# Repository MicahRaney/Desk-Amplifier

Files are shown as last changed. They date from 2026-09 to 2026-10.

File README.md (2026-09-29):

View this project on [CADLAB.io](https://cadlab.io/project/30623). 

All the desktop amps are either too cheap (passive), or too expensive (too many features).

This is a project to see if I can build what I want: a 3 input / 1 output simple mixer/amp
to allow my desk speakers to play audio from my laptop, desktop, and CD player at once

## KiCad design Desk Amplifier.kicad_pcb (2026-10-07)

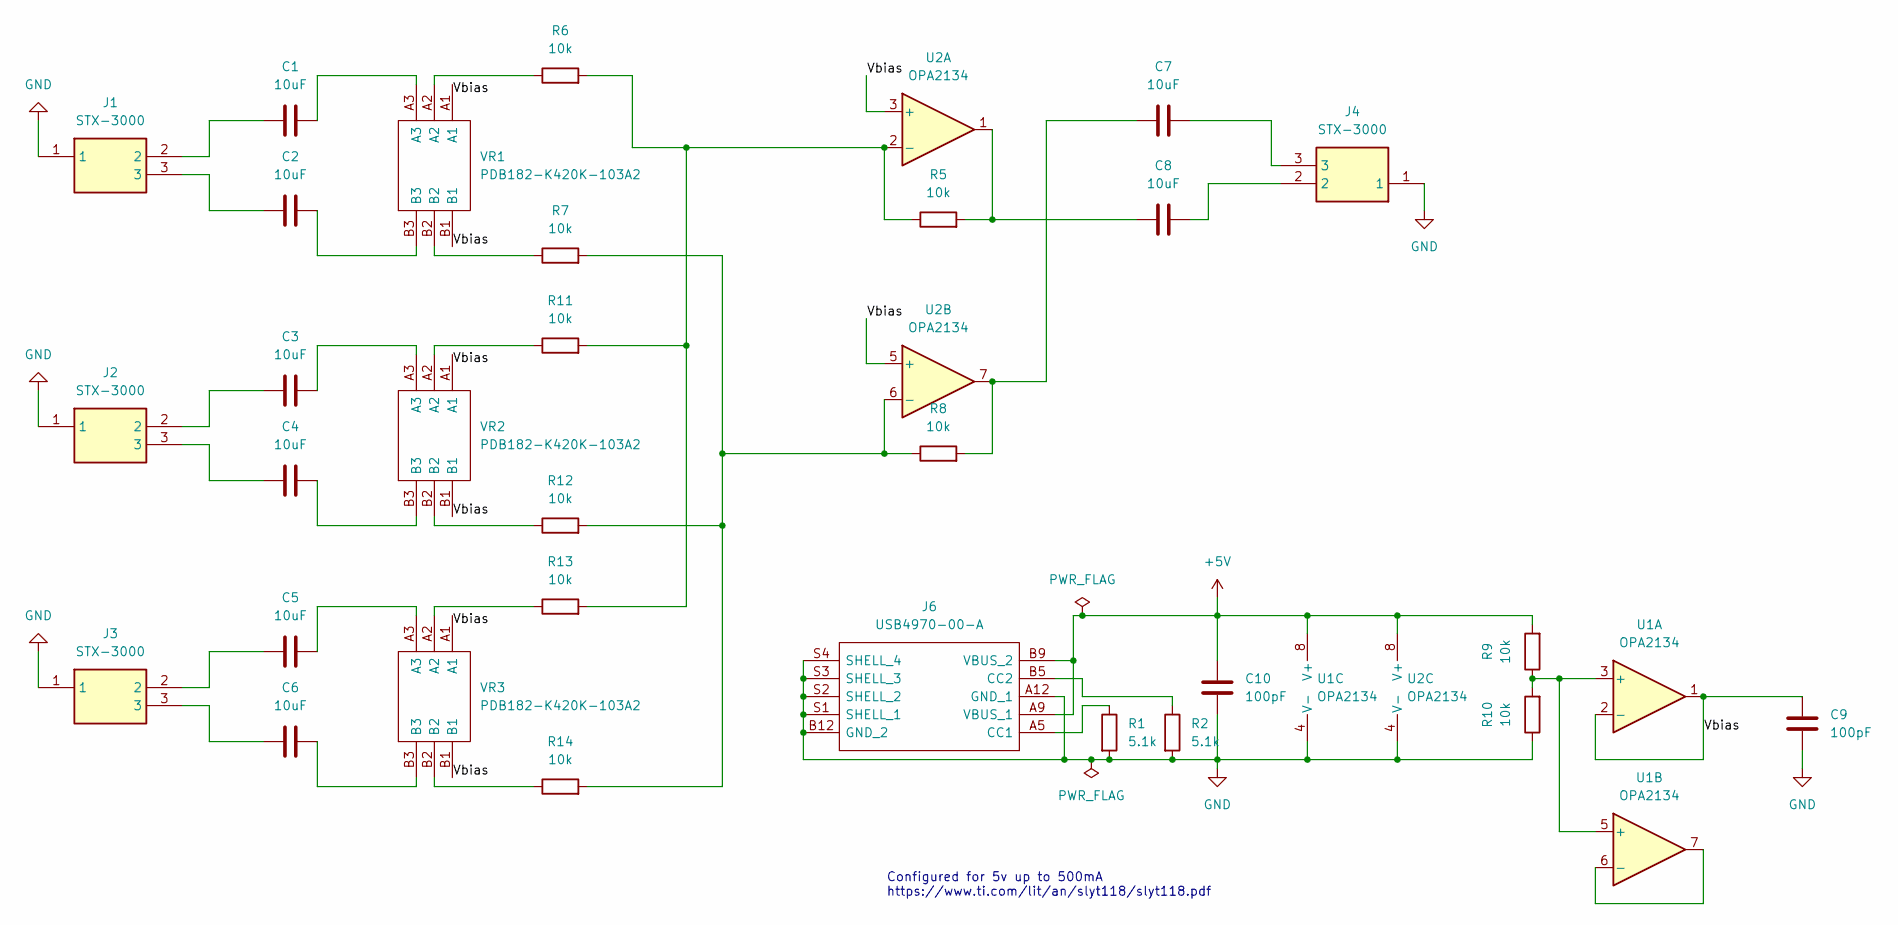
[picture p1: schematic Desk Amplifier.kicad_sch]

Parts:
C1, C2, C3, C4, C5, C6, C7, C8: 10uF; C_Disc_D10.0mm_W2.5mm_P5.00mm
C9, C10: 100pF; C_Disc_D10.0mm_W2.5mm_P5.00mm
J1, J2, J3, J4: STX-3000; STX3000; Manufacturer_Part_Number STX-3000; Mouser Part Number 806-STX-3000
J6: USB4970-00-A; USB497000A; Manufacturer_Part_Number USB4970-00-A
R1, R2: 5.1k; R_Axial_DIN0207_L6.3mm_D2.5mm_P7.62mm_Horizontal
R5, R6, R7, R8, R9, R10, R11, R12, R13, R14: 10k; R_Axial_DIN0207_L6.3mm_D2.5mm_P7.62mm_Horizontal
U1, U2: OPA2134; DIP-8_W7.62mm
VR1, VR2, VR3: PDB182-K420K-103A2; PDB182K420P204A2; Manufacturer_Part_Number PDB182-K420K-103A2; Mouser Part Number 652-PDB182K420K103A2

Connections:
+5V: C10.2, J6.A9 (VBUS_1), J6.B9 (VBUS_2), R9.2, U1.8 (V+), U2.8 (V+)
/Vbias: C9.2, U1.1, U1.2 (-), U2.3 (+), U2.5 (+), VR1.A1, VR1.B1, VR2.A1, VR2.B1, VR3.A1, VR3.B1
GND: C9.1, C10.1, J1.1, J2.1, J3.1, J4.1, J6.A12 (GND_1), J6.B12 (GND_2), J6.S1 (SHELL_1), J6.S2 (SHELL_2), J6.S3 (SHELL_3), J6.S4 (SHELL_4), R1.2, R2.2, R10.1, U1.4 (V-), U2.4 (V-)
unnamed: C1.1, J1.2
unnamed: C1.2, VR1.A3
unnamed: C2.1, J1.3
unnamed: C2.2, VR1.B3
unnamed: C3.1, J2.2
unnamed: C3.2, VR2.A3
unnamed: C4.1, J2.3
unnamed: C4.2, VR2.B3
unnamed: C5.1, J3.2
unnamed: C5.2, VR3.A3
unnamed: C6.1, J3.3
unnamed: C6.2, VR3.B3
unnamed: C7.1, R8.2, U2.7
unnamed: C7.2, J4.3
unnamed: C8.1, R5.2, U2.1
unnamed: C8.2, J4.2
unnamed: J6.A5 (CC1), R1.1
unnamed: J6.B5 (CC2), R2.1
unnamed: R6.1, VR1.A2
unnamed: R7.1, VR1.B2
unnamed: R11.1, VR2.A2
unnamed: R12.1, VR2.B2
unnamed: R13.1, VR3.A2
unnamed: R14.1, VR3.B2
unnamed: R9.1, R10.2, U1.3 (+), U1.5 (+)
unnamed: U1.6 (-), U1.7
unnamed: R5.1, R6.2, R11.2, R13.2, U2.2 (-)
unnamed: R7.2, R8.1, R12.2, R14.2, U2.6 (-)

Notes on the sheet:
Configured for 5v up to 500mA https://www.ti.com/lit/an/slyt118/slyt118.pdf

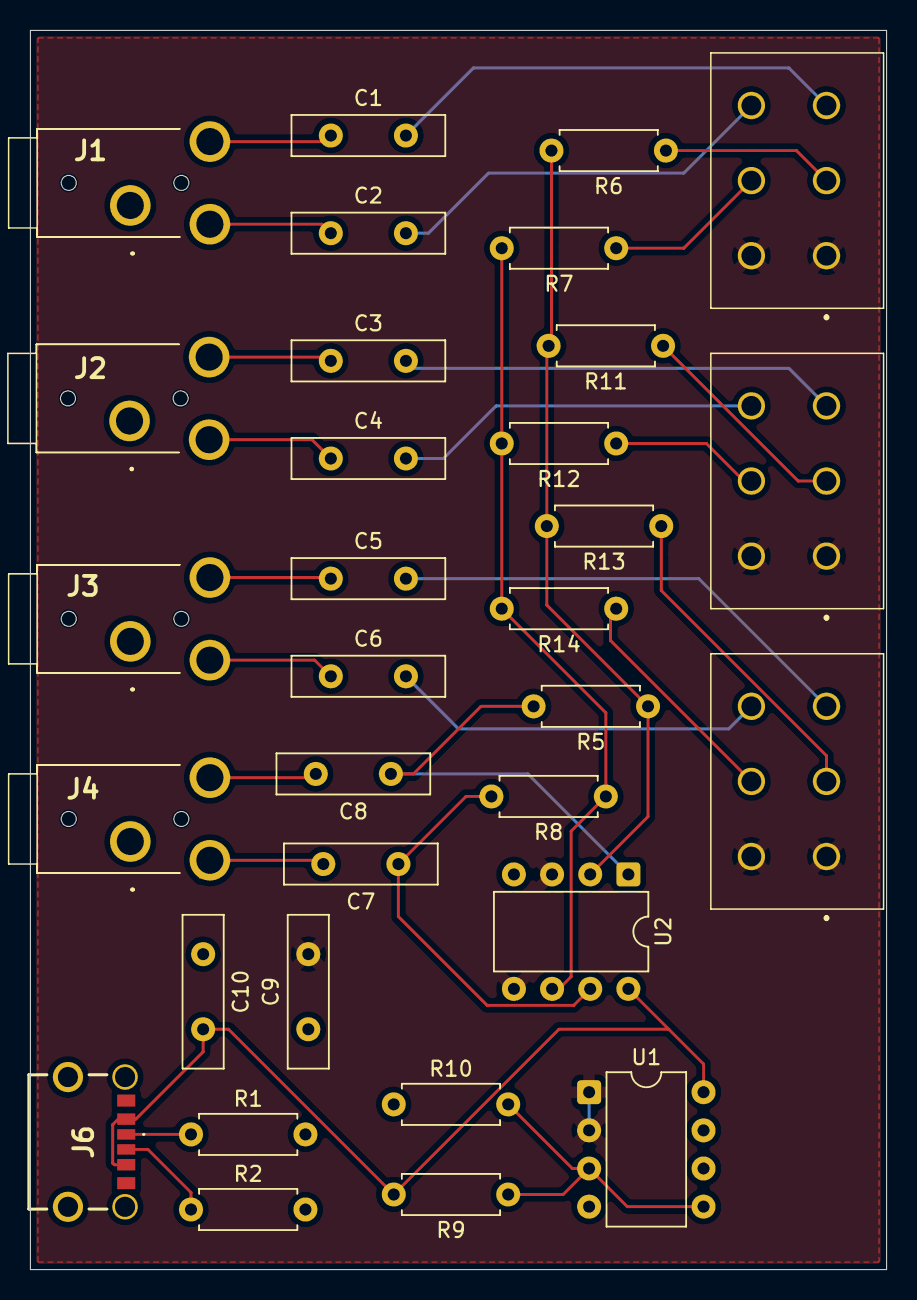
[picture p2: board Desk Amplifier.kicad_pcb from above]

Board: 2 copper layers, 57.0 x 82.5 mm, 32 parts (0 on the bottom side), 31 nets.

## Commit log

2026-09-29 first draft
    [Desk Amplifier.kicad_pcb, Desk Amplifier.kicad_sch]
2026-09-29 simplified version: passive input
    no pre-amp
    accept 180 phase shift
    [Desk Amplifier.kicad_sch]
2026-09-29 poc layout
    [Desk Amplifier.kicad_pcb, Desk Amplifier.kicad_sch]
2026-10-07 updated with real components
    [Desk Amplifier.kicad_pcb, Desk Amplifier.kicad_sch]
2026-10-07 use STX-3000 for 2.5mm jack connection + routing
    [Desk Amplifier.kicad_pcb, Desk Amplifier.kicad_sch]
2026-10-07 add vbias plane on f.cu, update j1-4 to protrude over edge
    [Desk Amplifier.kicad_pcb]
2026-10-14 Add 3d printed FreeCad case (WIP)
2026-10-20 update caps to correct 2.5mm pitch footprint
2026-10-20 update BOM to match ordered parts
2026-10-27 rework case to be closed on top
2026-10-27 add bottom case
2026-10-27 bottom case v1
2026-10-27 case step export
2026-11-02 update case
